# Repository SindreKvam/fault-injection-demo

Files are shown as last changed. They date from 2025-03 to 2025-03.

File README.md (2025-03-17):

# README

This repository contains code used to demonstrate a voltage glitch attack on a Arduino Nano Every.

## Fault Injection Demonstration

### Prerequisites

1. Desolder decoupling capacitors on Arduino development kit.
    - C2, C3, C4, C6, C8, C9, C10
    - **Note**: Removing C6 removes the option to program using USB.
2. Program FPGA DE10-Lite board by connecting USB, and flash the .sof file to the board.
    - To flash, use quartus programmer.

## FPGA code
All FPGA related code is found in the `fpga` folder.
There is a python script located in `fpga/uart_regs-1.0.4` that can be used to generate
UART vhdl modules and a python script that can be used to communicate with the UART modules.
This script generates files that are found in `fpga/generated`. If there is interest in 
adding more registers that are accessible over UART. Use the script, remember to include
the registers that are already generated. See any of the files found in the `fpga/generated`
folder to see the previously ran command.

Remember to run the command from the `fpga` folder.

## Simulations
Simulations of the system can be found in the `sim` folder.
The simulations are made using LTSpice and is only using default components.

## Schematic
Schematic and PCB has been designed using KiCad. See the `schematic` folder for the 
KiCad project files.

## Create Package

## License agreements

- MIT License for main project
    - License file: `./LICENSE`
- MIT License provided by VHDLwhiz for uart_regs tool.
    - License file: `./fpga/uart_regs-1.0.4/LICENSE.txt`

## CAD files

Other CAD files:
fpga/stp1.stp

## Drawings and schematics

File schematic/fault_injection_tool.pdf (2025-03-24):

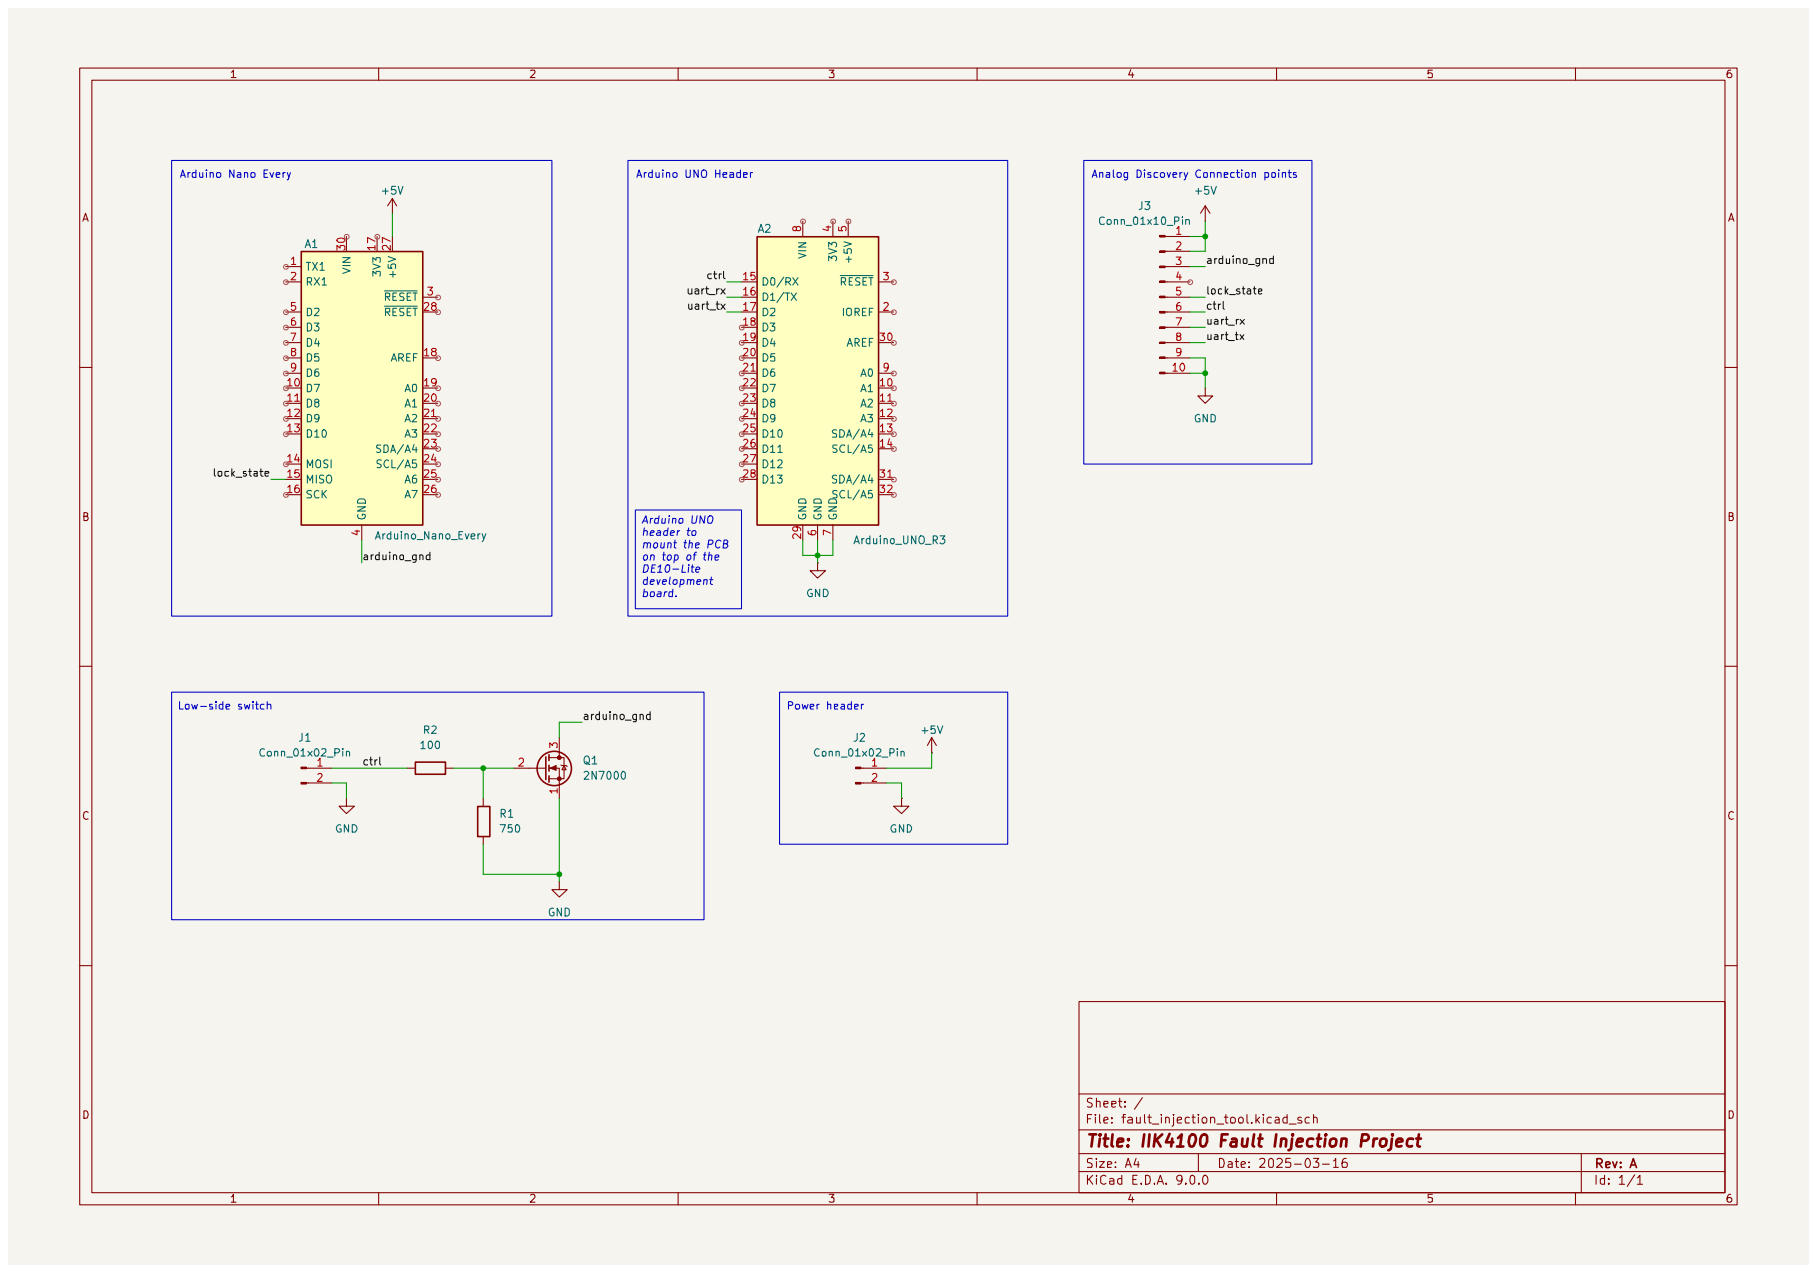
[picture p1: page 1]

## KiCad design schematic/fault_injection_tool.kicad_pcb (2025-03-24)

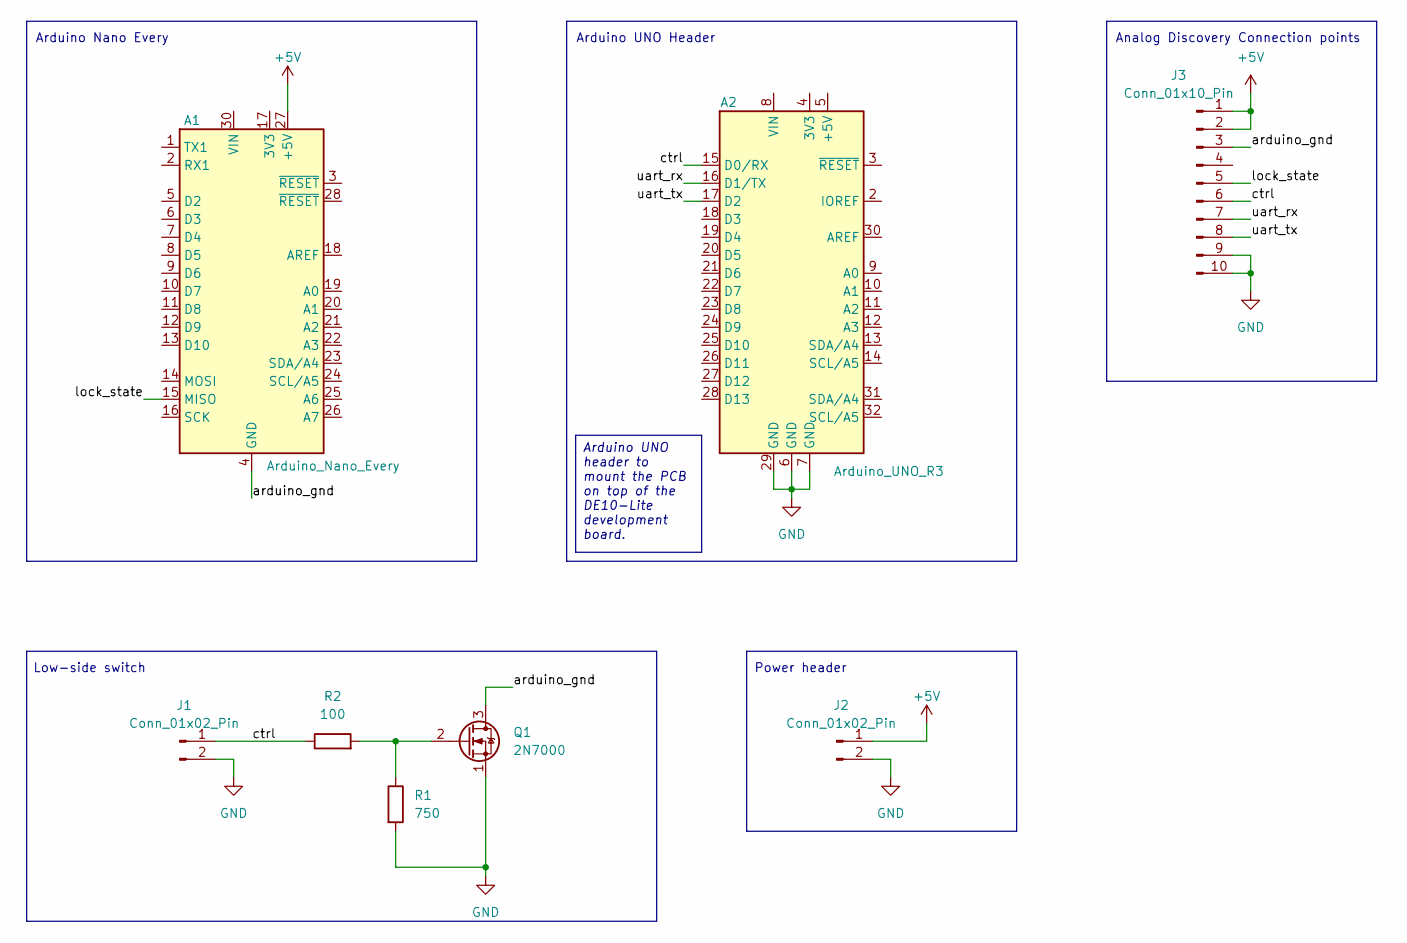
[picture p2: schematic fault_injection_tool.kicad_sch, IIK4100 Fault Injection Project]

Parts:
A1: Arduino_Nano_Every; Arduino_Nano
A2: Arduino_UNO_R3
J1, J2: Conn_01x02_Pin; PinHeader_1x02_P2.54mm_Vertical
J3: Conn_01x10_Pin; PinHeader_1x10_P2.54mm_Vertical
Q1: 2N7000; TO-92_Inline
R1: 750; R_0603_1608Metric_Pad0.98x0.95mm_HandSolder
R2: 100; R_0603_1608Metric_Pad0.98x0.95mm_HandSolder

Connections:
+5V: A1.27 (+5V), J2.1, J3.1, J3.2
/arduino_gnd: A1.4 (GND), A1.29 (GND), J3.3, Q1.3 (D)
/ctrl: A2.15 (D0/RX), J1.1, J3.6, R2.1
/lock_state: A1.15 (MISO), J3.5
/uart_rx: A2.16 (D1/TX), J3.7
/uart_tx: A2.17 (D2), J3.8
GND: A2.6 (GND), A2.7 (GND), A2.29 (GND), J1.2, J2.2, J3.9, J3.10, Q1.1 (S), R1.2
unnamed: Q1.2 (G), R1.1, R2.2

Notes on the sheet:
Arduino UNO Header
Arduino Nano Every
Analog Discovery Connection points
Low-side switch
Power header
Arduino UNO header to mount the PCB on top of the DE10-Lite development board.

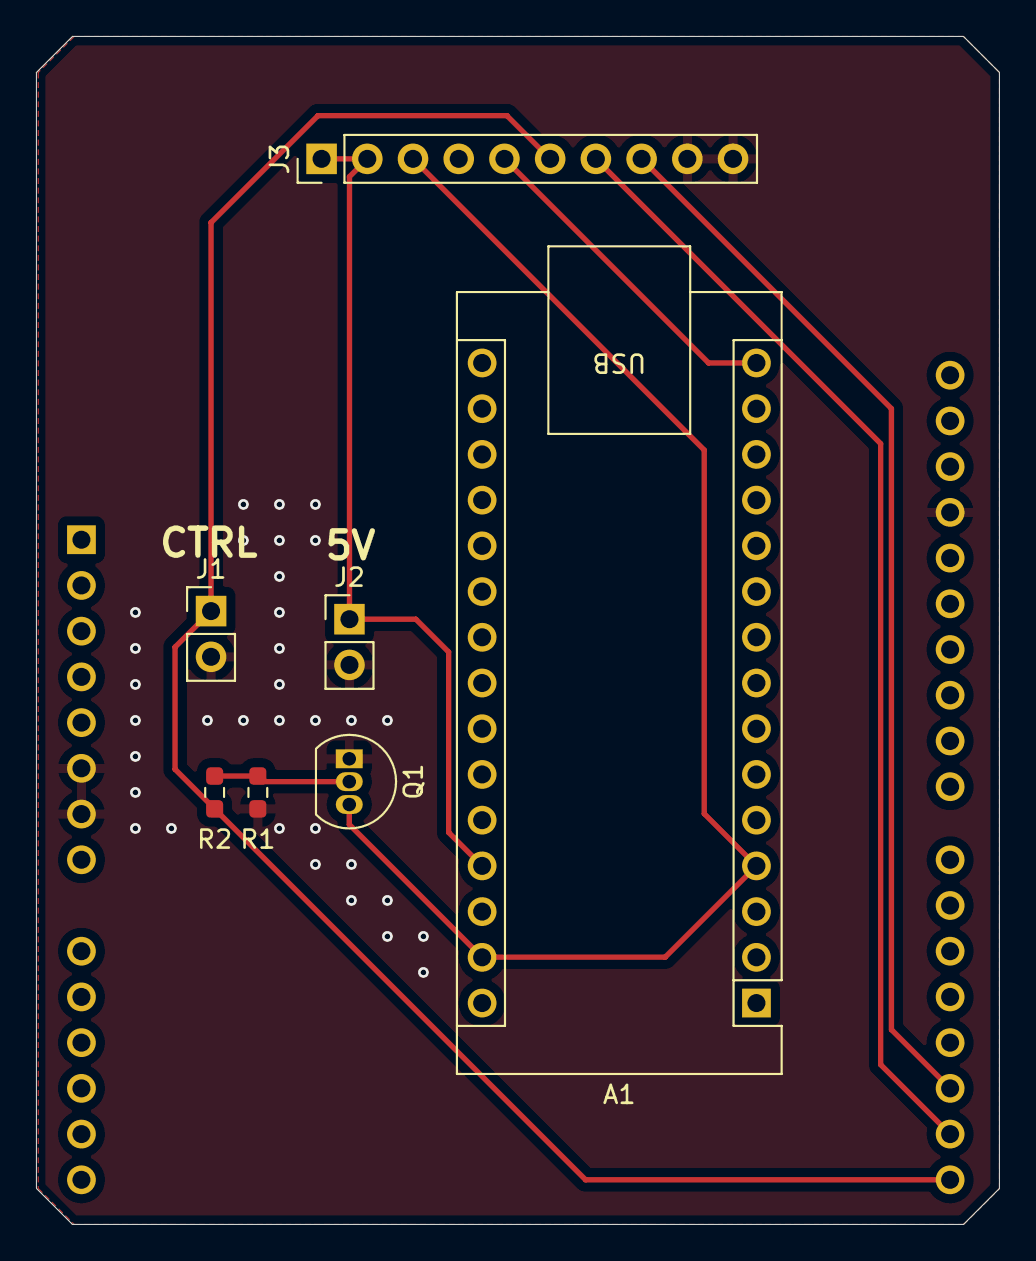
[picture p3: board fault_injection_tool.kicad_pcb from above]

Board: 2 copper layers, 53.5 x 66.0 mm, 8 parts (1 on the bottom side), 8 nets.

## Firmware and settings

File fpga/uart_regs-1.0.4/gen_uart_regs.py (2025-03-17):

"""Script by VHDLwhiz for generating UART accessible register module and accessor Python script"""

import os
import sys
import argparse
import textwrap

DEFAULT_UART_PORT = "COM7"
DEFAULT_BAUD_RATE = 115200


class RegisterAction(argparse.Action):
    def __call__(self, parser, namespace, values, option_string=None):
        registers = []

        for value in values:
            try:
                name, rest = value.split("=")

                if any(name == reg[0] for reg in registers):
                    parser.error(f"Register name '{name}' can only be used once")

                parts = rest.split(":")
                length_str = parts[0]
                length = int(length_str)
                mode_str = parts[1] if len(parts) > 1 else "in"
                type_str = (
                    parts[2]
                    if len(parts) > 2
                    else ("std_logic" if length == 1 else "std_logic_vector")
                )
                if length <= 0:
                    parser.error(
                        f"Bit length for register {name} must be a positive integer."
                    )
                if mode_str not in ["in", "out"]:
                    parser.error(
                        f"Invalid mode {mode_str} for register {name}. Valid modes are in or out."
                    )
                if type_str not in [
                    "unsigned",
                    "signed",
                    "std_logic_vector",
                    "std_logic",
                ]:
                    parser.error(
                        f"Invalid type {type_str} for register {name}. Valid types are unsigned, signed, std_logic_vector, or std_logic."
                    )
                if type_str == "std_logic" and length != 1:
                    parser.error(
                        f"Type 'std_logic' for register {name} must have a bit length of 1."
                    )
                registers.append((name, length, type_str, mode_str))

            except ValueError:
                parser.error(f"Invalid register specification {value}.")

        if not registers:
            parser.error(
                "No registers were supplied. At least one register must be specified."
            )

        setattr(namespace, self.dest, registers)


# Function to generate VHDL code based on the register information
def gen_vhdl_code(registers):
    vhdl_code = f"""-- UART register accessor by VHDLwhiz
-- Generated with the command:
-- python {" ".join(sys.argv)}
  
library ieee;
use ieee.std_logic_1164.all;
use ieee.numeric_std.all;

entity uart_regs is
  generic (
    clk_hz : positive;
    baud_rate : positive := {DEFAULT_BAUD_RATE}
  );
  port (
    clk : in std_logic;
    rst : in std_logic;

    uart_rx : in std_logic;
    uart_tx : out std_logic;

    -- UART accessible registers
"""

    in_total_length = 0
    out_total_length = 0
    for i, (name, length, type_str, mode_str) in enumerate(registers):
        separator = ";" if i < len(registers) - 1 else ""
        type_declaration = f"{type_str}({length-1} downto 0)" if length > 1 else type_str
        vhdl_code += f"    {name} : {mode_str} {type_declaration}{separator}\n"
        if mode_str == "in":
            in_total_length += length
        else:
            out_total_length += length

    # Make in_total_length and out_total_length multiples of 8
    in_total_length = ((in_total_length + 7) // 8) * 8
    out_total_length = ((out_total_length + 7) // 8) * 8

    vhdl_code += """  );
end uart_regs;

architecture rtl of uart_regs is\n\n"""

    in_bytes = (in_total_length + 7) // 8
    out_bytes = (out_total_length + 7) // 8

    if in_total_length > 0:
        vhdl_code += f"  signal in_regs : std_logic_vector({in_total_length-1} downto 0) := (others => '0');\n"
    if out_total_length > 0:
        vhdl_code += (
            f"  signal out_regs : std_logic_vector({out_total_length-1} downto 0);\n"
        )

    vhdl_code += "\nbegin\n\n"

    in_upper_bound = in_total_length - 1
    out_upper_bound = out_total_length - 1
    for name, length, type_str, mode_str in reversed(registers):
        if length == 1:
            slice_str = f"{in_upper_bound}" if mode_str == "in" else f"{out_upper_bound}"
        else:
            slice_str = (
                f"{in_upper_bound} downto {in_upper_bound - length + 1}"
                if mode_str == "in"
                else f"{out_upper_bound} downto {out_upper_bound - length + 1}"
            )

        if mode_str == "in":
            slice_str = f"in_regs({slice_str})"
            in_upper_bound -= length
            if type_str in ["unsigned", "signed"]:
                slice_str = f"{slice_str} <= std_logic_vector({name});"
            else:
                slice_str = f"{slice_str} <= {name};"
            vhdl_code += f"  {slice_str}\n"
        else:
            slice_str = f"out_regs({slice_str})"
            out_upper_bound -= length
            if type_str == "unsigned":
                slice_str = f"unsigned({slice_str})"
            elif type_str == "signed":
                slice_str = f"signed({slice_str})"
            vhdl_code += f"  {name} <= {slice_str};\n"

    vhdl_code += """
  BACKEND : entity work.uart_regs_backend(rtl)
    generic map (
      clk_hz => clk_hz,
      baud_rate => baud_rate,
      in_bytes => {},
      out_bytes => {}
    )
    port map (
      clk => clk,
      rst => rst,
      uart_rx => uart_rx,
      uart_tx => uart_tx,
      in_regs => {},
      out_regs => {}
    );
""".format(
        in_bytes,
        out_bytes,
        "in_regs" if in_total_length > 0 else '""',
        "out_regs" if out_total_length > 0 else "open",
    )

    vhdl_code += "\nend architecture;"

    return vhdl_code


def gen_python_code(registers):
    python_code = f"""# UART register accessor by VHDLwhiz
# Generated with the command:
# python {" ".join(sys.argv)}

import math
import argparse
import serial
from serial.tools.list_ports import comports

# UART accessible register structure:
# (Name, Mode, Bit Length, Data Type)
registers = [
"""

    for name, length, type_str, mode_str in registers:
        python_code += f"    ('{name}', '{mode_str}', {length}, '{type_str}'),\n"

    python_code += (
        "]"
        + f"""

# Default UART configuration
UART_PORT = \"{DEFAULT_UART_PORT}"
BAUD_RATE = {DEFAULT_BAUD_RATE}"""
        + """

# Protocol constants
READ_REQ = 0x0A
START_WRITE = 0x0B
END_WRITE = 0x0C
ESCAPE = 0x0D

class UartRegs:

    def __init__(self, port, baud_rate, debug=False):
        \"""UART access to FPGA registers by VHDLwhiz.com
        Set debug=True to enable printing of sent and received bytes.\"""

        self.debug = debug
        if self.debug:
            print(f"Opening UART_PORT: {port} at baud rate: {baud_rate}")
        self.ser = serial.Serial(port, baud_rate, timeout=1)

    def print_byte_debug(self, byte):
        protocol_constants = {
            READ_REQ: "READ_REQ",
            START_WRITE: "START_WRITE",
            END_WRITE: "END_WRITE",
            ESCAPE: "ESCAPE"
        }
        hex_str = f"{byte:02x}"
        control_char_info = protocol_constants.get(byte, "")
        if control_char_info:
            print(f"{hex_str} - {control_char_info}")
        else:
            print(hex_str)

    def read_regs(self):
        \"""Read all input and output registers and return a dict with the values on the form:
        {reg_name: value, ...}  Ex.: {'s3': 15, 's2': 13, 's1': 1}\"""
        
        # Calculate lengths of in_regs and out_regs
        in_regs_length = sum(reg[2] for reg in registers if reg[1] == 'in')
        out_regs_length = sum(reg[2] for reg in registers if reg[1] == 'out')
        
        # Pad lengths to multiples of 8
        in_regs_length = math.ceil(in_regs_length / 8) * 8
        out_regs_length = math.ceil(out_regs_length / 8) * 8

        # Calculate the expected number of bytes based on the registers
        expected_bytes = (in_regs_length + out_regs_length) // 8

        if self.debug:
            print("Sending Read request:")
            self.print_byte_debug(READ_REQ)
        self.ser.write(bytes([READ_REQ]))

        prev_byte = None
        receiving_data = True
        escape_next = False
        data = bytearray()

        if self.debug:
            print("Receiving bytes (hex):")

        # Read data from UART
        while True:
            byte = self.ser.read(1)
            if not byte:
                print("Read timed out")
                exit(1)

            byte = byte[0]
            
            if self.debug:
                self.print_byte_debug(byte)

            if byte == START_WRITE and prev_byte != ESCAPE:
                receiving_data = True
            elif receiving_data:
                if byte == END_WRITE and not escape_next:
                    receiving_data = False
                    break
                elif byte != ESCAPE or escape_next:
                    data.append(byte)
                    escape_next = False
                elif byte == ESCAPE:
                    escape_next = True
            prev_byte = byte

        # Check if the number of read data bytes matches the expected number
        if len(data) != expected_bytes:
            raise IOError(f"Received {len(data)} bytes, but expected {expected_bytes} bytes.")

        # Extract register values
        regs_values = {}
        start_bit_in = 0
        start_bit_out = 0
        in_regs = "".join([f"{byte:08b}" for byte in data[-(in_regs_length // 8):]])[-in_regs_length:]
        out_regs = "".join([f"{byte:08b}" for byte in data[:out_regs_length // 8]])[-out_regs_length:]

        def extract_bits(value, start, end):
            return value[start:end + 1]

        for name, mode, length, _ in reversed(registers):
            if mode == 'in':
                end_bit = start_bit_in + length
                value = extract_bits(in_regs, start_bit_in, end_bit - 1)
                start_bit_in = end_bit
            else:
                end_bit = start_bit_out + length
                value = extract_bits(out_regs, start_bit_out, end_bit - 1)
                start_bit_out = end_bit

            # Convert the binary string value to an integer
            regs_values[name] = int(value, 2)

        return regs_values

    @classmethod
    def print_table(cls, header_cols, rows, include_int_val=False, regs_values=None):
        # Determine the widths for each column
        widths = [max(len(col), max(len(str(row[i])) for row in rows)) + 2 for i, col in enumerate(header_cols)]

        # Construct the header line
        header = "".join([f"{col:<{width}}" for col, width in zip(header_cols, widths)])

        # Construct the separator line
        separator = "=" * len(header)

        # Print the header and separator
        print(header)
        print(separator)

        # Print the table rows
        for row in rows:
            print("".join([f"{str(item):<{widths[i]}}" for i, item in enumerate(row)]))

    def print_regs(self, regs_values):
        \"""Print a nice ASCII table with the reg values returned by read_regs()\"""

        header_cols = ["Reg name", "Bits", "Type", "Mode", "Hex val"]
        has_int_val = any(data_type in ['unsigned', 'signed'] for _, _, _, data_type in registers)
        
        if has_int_val:
            header_cols.append("Int val")
        
        rows = [[name, str(length), data_type, mode, hex(regs_values[name])] for name, mode, length, data_type in registers]
        
        if has_int_val:
            for row in rows:
                value = regs_values[row[0]]
                int_val = ""
                if row[2] == 'unsigned':
                    int_val = value
                elif row[2] == 'signed':
                    bit_length = int(row[1])
                    int_val = value - (1 << bit_length) if value & (1 << (bit_length - 1)) else value

                row.append(int_val)
        self.print_table(header_cols, rows)
    
    def read_and_print_regs(self):
        \"""Read and print all registers in a nice ASCII table\"""

        all_values = self.read_regs()
        self.print_regs(all_values)

    @classmethod
    def list_regs(cls):
        header_cols = ["Register Name", "Bits", "Type", "Mode"]
        rows = [[name, str(length), data_type, mode] for name, mode, length, data_type in registers]
        cls.print_table(header_cols, rows)

    def write_regs(self, write_values):
        \"""Takes a dict with the register names and values to write on the form:
        {reg_name: value} Ex. {'s1': 1, 's2': 15, 's3': 255}
        
        If a complete set of output values isn't given this method will
        use read_regs() to get the current values for the missing registers before writing.\"""

        write_values = self.read_back_missing_out_regs(write_values)

        # Build the write data from the register values
        write_data_bits = ""
        for name, mode, length, data_type in reversed(registers):
            if mode == 'out':
                value = write_values[name]
                
                # Check if the value is in the valid range for the given data type
                if data_type == 'signed':
                    if value >= (1 << (length - 1)) or value < -(1 << (length - 1)):
                        raise ValueError(f"The value {value} for register {name} exceeds the {length}-bit length allowed for signed.")
                else:
                    if value < 0 or value >= (1 << length):
                        raise ValueError(f"The value {value} for register {name} exceeds the {length}-bit length allowed for unsigned.")

                if data_type == 'signed' and value < 0:
                    value_bits = f"{value & ((1 << length) - 1):0{length}b}" # Two's complement for negative values
                else:
                    value_bits = f"{value:0{length}b}"
                
                write_data_bits += value_bits

        # Pad the write data to 8-bit boundaries
        padding_length = (8 - len(write_data_bits) % 8) % 8
        write_data_bits += "0" * padding_length

        # Convert to bytes and escape control characters
        write_bytes = bytearray()
        write_bytes.append(START_WRITE) # Directly append the integer

        for i in range(0, len(write_data_bits), 8):
            byte_value = int(write_data_bits[i:i + 8], 2)
            if byte_value in [READ_REQ, START_WRITE, END_WRITE, ESCAPE]: # Directly use the integers
                write_bytes.append(ESCAPE) # Directly append the integer
            write_bytes.append(byte_value)
        write_bytes.append(END_WRITE) # Directly append the integer

        if self.debug:
            print("Sending bytes (hex):")

            for b in write_bytes:
                self.print_byte_debug(b)

        # Send the write data
        bytes_written = self.ser.write(write_bytes)

        # Check that all bytes were written
        if bytes_written != len(write_bytes):
            raise IOError(f"Write failed! {bytes_written} bytes written out of {len(write_bytes)}")

    def read_back_missing_out_regs(self, write_values):
        \"""Read the current value of any output registers that are missing from write_values.
        Return a complete list of all output registers that can be used to write them to the target.\"""

        # Create a copy of the provided write values to avoid modifying the original object
        complete_write_values = write_values.copy()

        # Check if any out-mode registers are missing
        missing_values = [name for name, mode, _, _ in registers if mode == 'out' and name not in complete_write_values]

        if missing_values:

            if self.debug:
                print("Reading the currect values from the target before updating the outputs")

            # Read current values of all registers if there are missing out-mode values
            current_values = self.read_regs()

            # Fill in missing values for "out" registers
            for name in missing_values:
                complete_write_values[name] = current_values[name]

        return complete_write_values
    

if __name__ == "__main__":

    class WriteAction(argparse.Action):
        def __call__(self, parser, namespace, values, option_string=None):
            # Ensure that at least one out-mode register value is provided
            if len(values) < 1:
                parser.error("argument -w/--write: must provide at least one out-mode register value in the format reg_name=value.")

            # Parse the provided values into a dictionary
            write_values = {name: int(value, 0) for name, value in (v.split('=') for v in values)}
            
            # Validate that the provided names correspond to out-mode registers
            out_register_names = [name for name, mode, _, _ in registers if mode == 'out']
            for name in write_values.keys():
                if name not in out_register_names:
                    parser.error(f"argument -w/--write: {name} is not a valid out-mode register name.")

            setattr(namespace, self.dest, write_values)
    
    def list_available_com_ports():
        ports = comports()
        available_ports = [port.device for port in ports]
        return available_ports
    
    parser = argparse.ArgumentParser(
        description="Command-line interface to read from and write to UART-accessible registers by VHDLwhiz",
        epilog="Example: 'python uart_regs.py -w reg1=255 reg2=0xff reg3=0b11111111'. "
           "This will write 255 to 'reg1', 'reg2', and 'reg3'."
    )

    group = parser.add_mutually_exclusive_group(required=True)
    group.add_argument('-r', '--read', action='store_true', help='Read all registers')
    group.add_argument('-w', '--write', nargs='*', action=WriteAction, metavar='reg_name=value',
                   help='Write to one or more out mode registers. The value can be given as hex (e.g., 0xff), '
                        'binary (e.g., 0b1111), or as a signed or unsigned integer.')
    group.add_argument('-l', '--list', action='store_true', help='List all registers')
    parser.add_argument('-d', '--debug', action='store_true', help='Print debugging info about received and sent bytes')

    available_ports = list_available_com_ports()
    parser.add_argument('-c', '--com', default=UART_PORT, help=f'Set the UART port. Default is {UART_PORT}'
        f' as defined in the UART_PORT constant. Available ports: {", ".join(available_ports)}')

    args = parser.parse_args()

    if args.list:
        UartRegs.list_regs()
    else:

        uart_regs = UartRegs(port=args.com, baud_rate=BAUD_RATE, debug=args.debug)

        if args.read:
            uart_regs.read_and_print_regs()
        elif args.write:
            uart_regs.write_regs(args.write)
            print("Write succeeded")"""
    )

    return python_code


def gen_inst_template(registers):
    template = f"""-- UART register accessor by VHDLwhiz

  constant clk_hz : integer := 100e6;

  signal clk : std_logic;
  signal rst : std_logic;
  signal uart_to_dut : std_logic;
  signal uart_from_dut : std_logic;

  -- UART accessible registers"""

    for name, length, data_type, mode in registers:
        if data_type == "std_logic":
            template += f"""
  signal {name} : {data_type};"""
        else:
            template += f"""
  signal {name} : {data_type}({length - 1} downto 0);"""

    template += f"""

begin

  -- Generated with the command:
  -- python {" ".join(sys.argv)}
  UART_REGS_INST : entity work.uart_regs(rtl)
  generic map (
    clk_hz => clk_hz
  )
  port map (
    clk => clk,
    rst => rst,
    uart_rx => uart_rx,
    uart_tx => uart_tx,"""

    for name, _, _, _ in registers:
        template += f"""
    {name} => {name},"""

    # Remove trailing comma and close the port map
    template = template[:-1]
    template += """
  );
  """

    return template
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

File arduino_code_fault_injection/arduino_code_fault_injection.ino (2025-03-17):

#define LOCK_STATE_PIN 12
#define BUILT_IN_LED_PIN 13

volatile int a = 1, b = 1, c = 1, d = 1;

void setup() {

  pinMode(LOCK_STATE_PIN, OUTPUT);
  pinMode(BUILT_IN_LED_PIN, OUTPUT);

  // Set locked pin high
  digitalWrite(LOCK_STATE_PIN, HIGH);
  digitalWrite(BUILT_IN_LED_PIN, HIGH);

  while(a == b && b == c && c == d) {

    // Do calculations where every variable should be the same at every check
    for(int i = 1; i < 1000; i++){a = (a + i);}
    for(int j = 1; j < 1000; j++){b = (b + j);}
    for(int k = 1; k < 1000; k++){c = (c + k);}
    for(int l = 1; l < 1000; l++){d = (d + l);}

  }

  digitalWrite(LOCK_STATE_PIN, LOW);

}

void loop(){
  // Indicate that the device is unlocked by alternating the LED.
  digitalWrite(BUILT_IN_LED_PIN, LOW);
  delay(500);
  digitalWrite(BUILT_IN_LED_PIN, HIGH);
  delay(500);
}

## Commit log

2025-03-12 Added API for powersupply to control power to the DUT
2025-03-12 Added simulation of comparator circuit for power delivery to arduino
2025-03-16 Updated arduino code, now using pins to indicate if hack has been performed
2025-03-16 Added various simulations, found circuit that works nicely
2025-03-16 Initial commit of fault injection tool schematic
    [fault_injection_tool.kicad_pcb, fault_injection_tool.kicad_sch]
2025-03-17 Added uart_regs tool
2025-03-17 Added generated uart register files
2025-03-17 Updated project files
    [stp1.stp]
2025-03-17 Updated arduino firmware
2025-03-17 Updated schematic drawing and PCB design
    [fault_injection_tool.kicad_pcb, fault_injection_tool.kicad_sch]
2025-03-17 Added extra register that can be accessed using UART
2025-03-18 Made some changes to the schematic
    [fault_injection_tool.kicad_pcb, fault_injection_tool.kicad_sch]
2025-03-24 Updated script to run attack to also add delayed lock state to find if device reset. Added script to analyze data
2025-03-24 Updated schematic and pcb layout
    [fault_injection_tool.kicad_pcb, fault_injection_tool.kicad_sch]
